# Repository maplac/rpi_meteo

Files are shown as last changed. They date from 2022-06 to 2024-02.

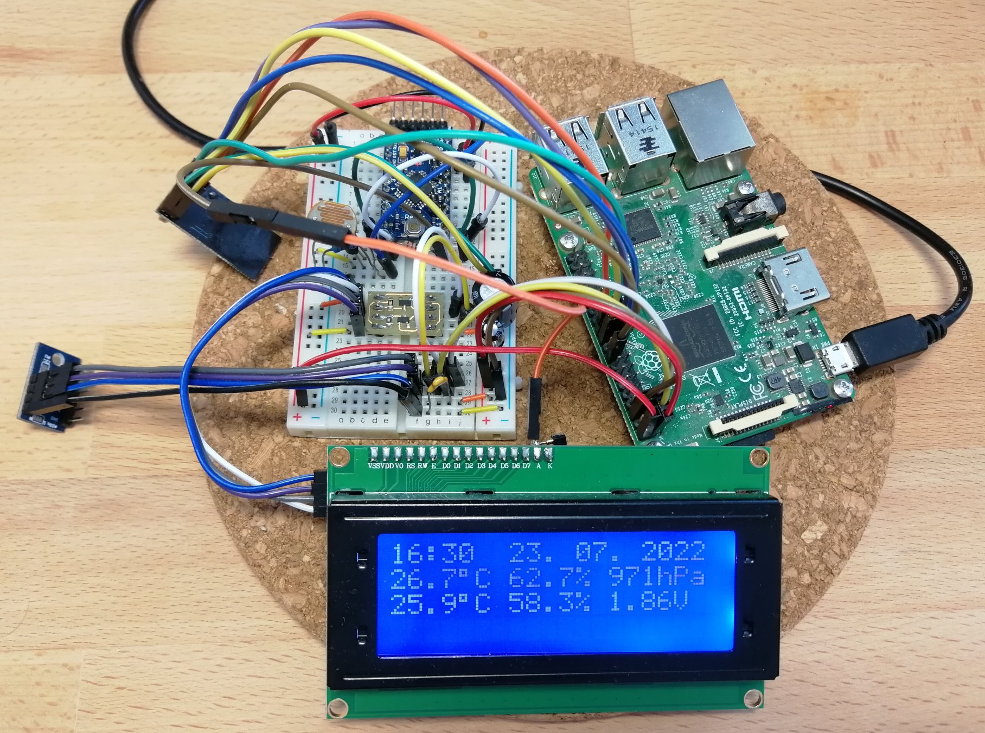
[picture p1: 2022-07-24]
photos/rpi_electronics_on_breadboard.jpg

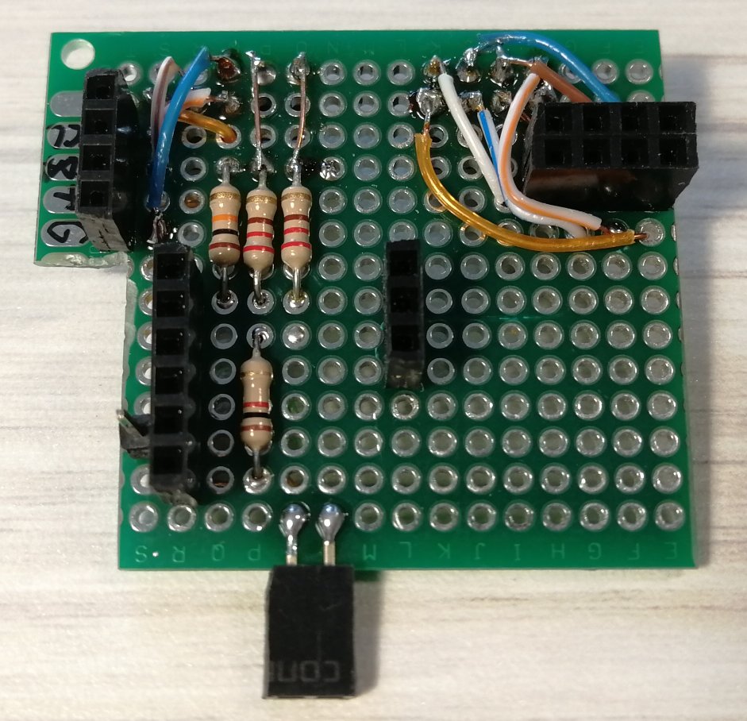
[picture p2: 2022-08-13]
photos/base_top_revA.jpg

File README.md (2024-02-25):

# rpi_meteo

Installation (incomplete)

Install Influx and Grafana.
https://simonhearne.com/2020/pi-influx-grafana/
"sudo apt install influxdb-client" if command influx doesn't work.

Add cron jobs.
$ crontab -e
* * * * * python3 /home/pi/rpi_meteo/python/bme280_reader.py >/dev/null 2>&1
# old driver for I2C 20x4 LCD display (not used enymore)
#* * * * * python3 /home/pi/rpi_meteo/python/lcd_driver.py >/dev/null 2>&1

Make sure the pigpiod service is enabled and running (required by rf24_receiver).
$ systemctl status pigpiod

Make the 'brightness' file editable by non-root user (required by backlight_driver).
sudo touch /etc/udev/rules.d/backlight-permissions.rules
sudo echo "SUBSYSTEM==\"backlight\",RUN+=\"/bin/chmod 666 /sys/class/backlight/%k/brightness /sys/class/backlight/%k/bl_power\"" > /etc/udev/rules.d/backlight-permissions.rules

Install service.
sudo cp /home/pi/rpi_meteo/python/rf24_receiver.service /lib/systemd/system/rf24_receiver.service
sudo systemctl start rf24_receiver
sudo systemctl enable rf24_receiver

sudo cp /home/pi/rpi_meteo/python/backlight_driver.service /lib/systemd/system/backlight_driver.service
sudo systemctl start backlight_driver
sudo systemctl enable backlight_driver

Install 'unclutter' to hide mouse cursor.
sudo apt install unclutter

Starting Grafana in web browser automatically after boot

Install Firefox (Chromium stopped working on my Rpi) $sudo apt-get install firefox-esr
Install ForceFull addon in Firefox. The addon automatically switches the Firefox to fullscreen mode.

Doesn't work:
Add following lines to file /home/pi/.config/lxsession/LXDE-pi/autostart
@lxpanel --profile LXDE-pi
@pcmanfm --desktop --profile LXDE-pi
#@xscreensaver -no-splash
point-rpi
@unclutter -idle 0
@firefox -url  http://localhost:3000/d/uZDC-7zgk/rpi_meteo-testing-simple?orgId=1&refresh=1m&kiosk
Do work:
Use firefox_starter.service or start_firefox_with_delay, one of them probably works.
Append "@unclutter -idle 0" to /etc/xdg/lxsession/LXDE-pi/autostart.

Modify InfluxDB settings to reduce CPU and RAM usage.
[data]
cache-max-memory-size = "512m"
max-concurrent-compactions = 2
[monitor]
store-enabled = false
From https://github.com/nikobockerman/ruuvitags-raspberrypi/tree/master/influxdb#initial-creation

Stop and disable telegraf.
systemctl disable telegraf

Grafana
Install Clock plugin.
sudo grafana-cli plugins install grafana-clock-panel
sudo systemctl restart grafana-server
Configure datasources

Arduino UNO project in test folder is based on https://github.com/bjarne-hansen/py-nrf24/blob/master/arduino/simple-sender/simple-sender.ino
Testing Python script rf24_receiver_01.py is based on https://github.com/bjarne-hansen/py-nrf24/blob/master/test/int-receiver.py

usermod -a - G gpio pi
usermod -a - G dialout pi
usermod -a - G i2c pi
Enable i2c and serial in "raspi-config".

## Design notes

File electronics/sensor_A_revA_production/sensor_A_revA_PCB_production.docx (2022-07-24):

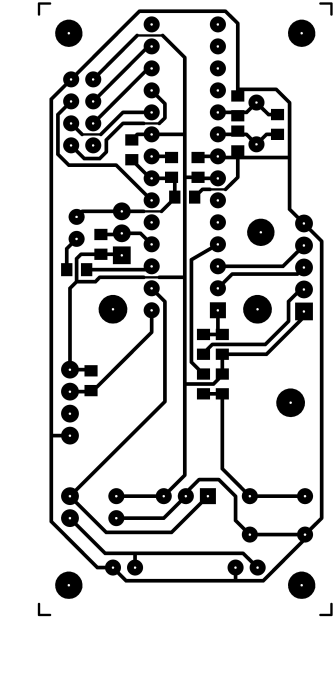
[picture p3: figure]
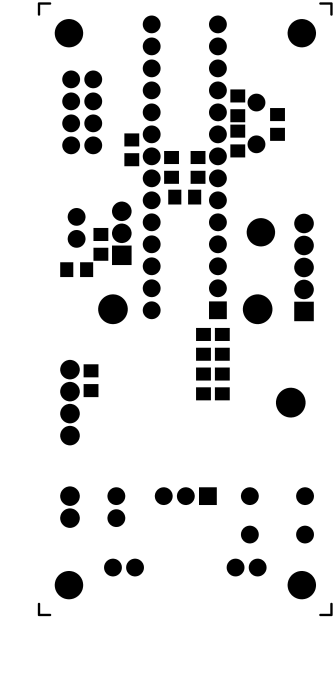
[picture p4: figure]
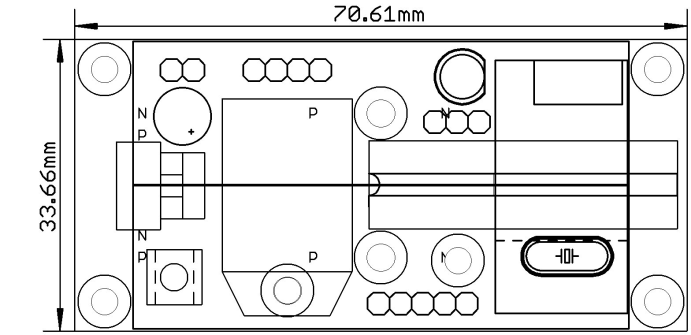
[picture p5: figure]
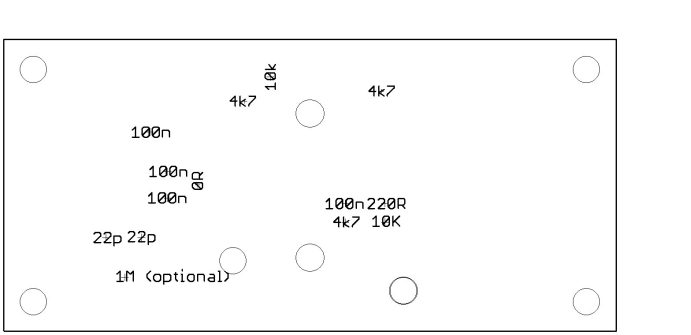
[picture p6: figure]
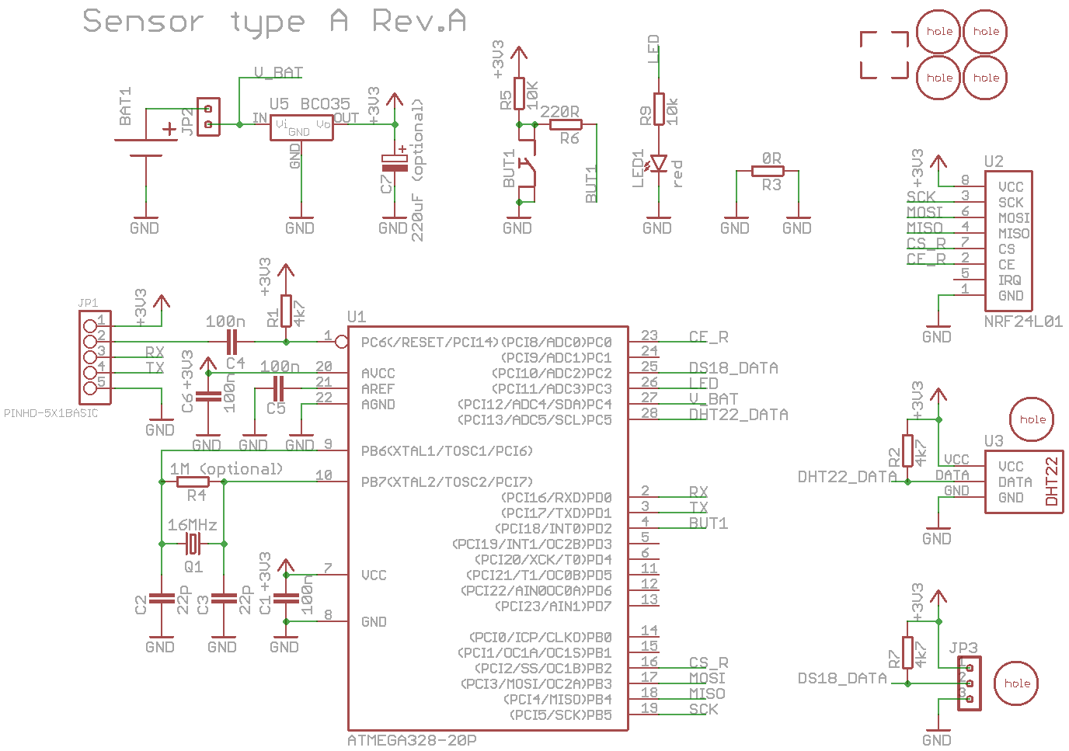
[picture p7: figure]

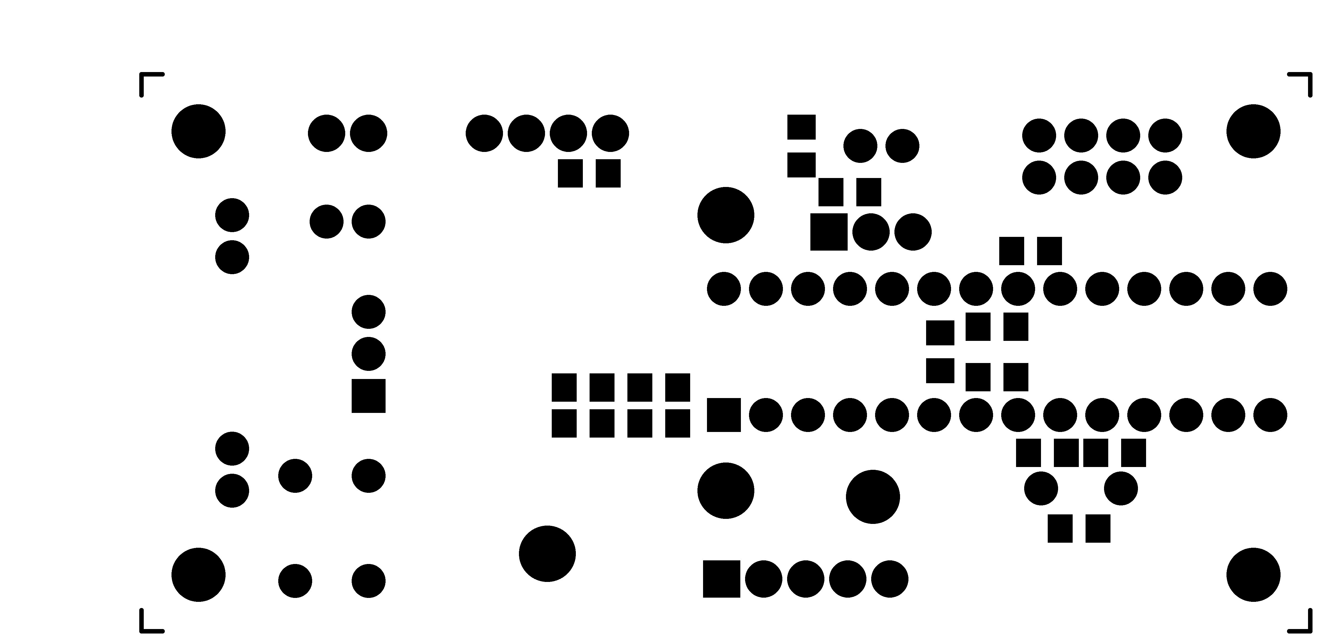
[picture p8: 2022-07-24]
electronics/sensor_A_revA_production/bottom_mask.jpg

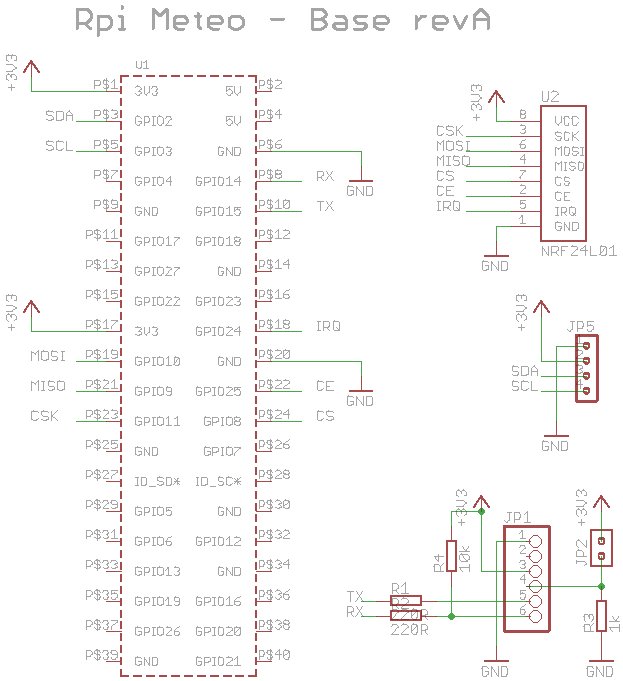
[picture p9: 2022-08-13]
electronics/base_revA_production/schematics.jpg

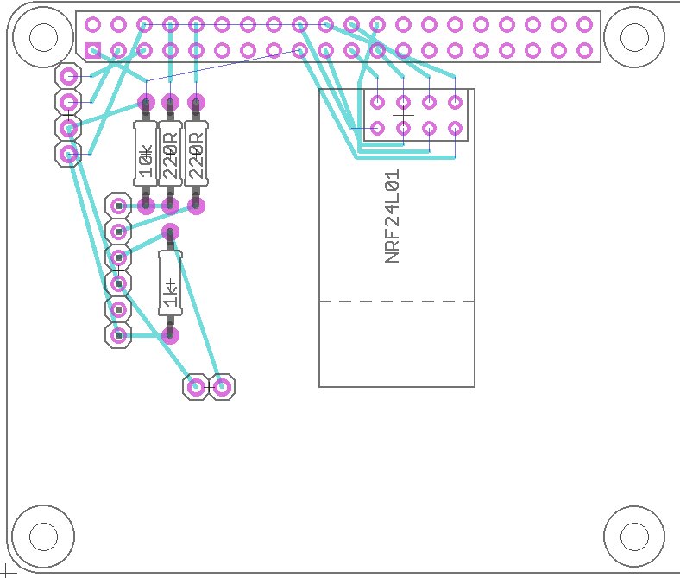
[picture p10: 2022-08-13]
electronics/base_revA_production/bottom&top.jpg

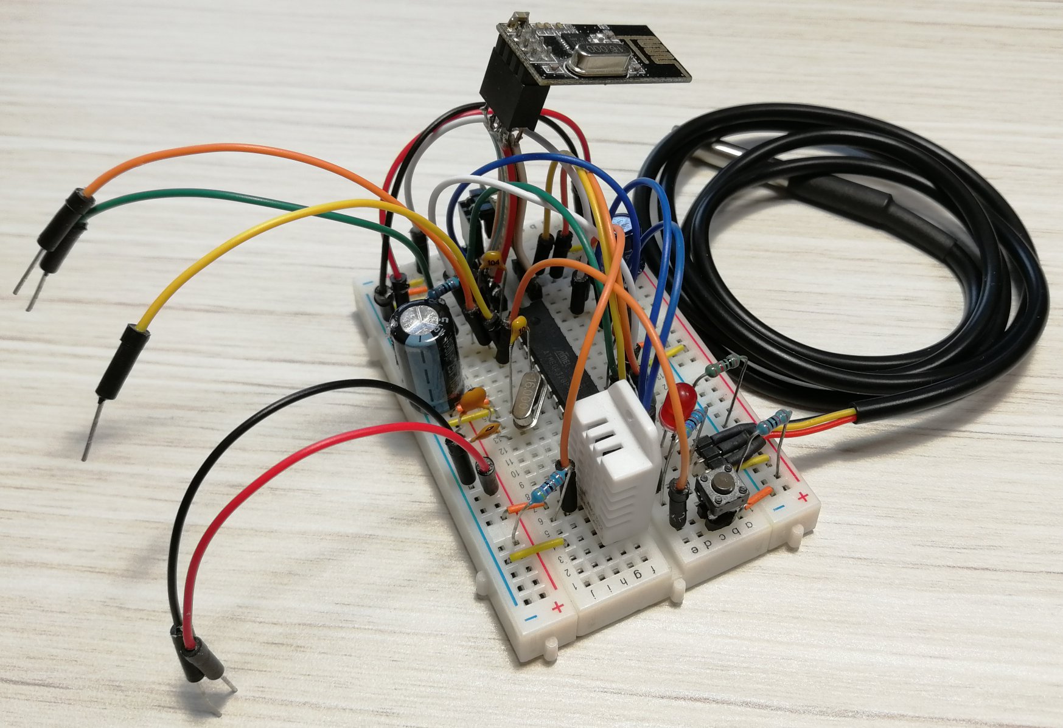
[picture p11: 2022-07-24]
photos/sensor_A_on_breadboard.jpg

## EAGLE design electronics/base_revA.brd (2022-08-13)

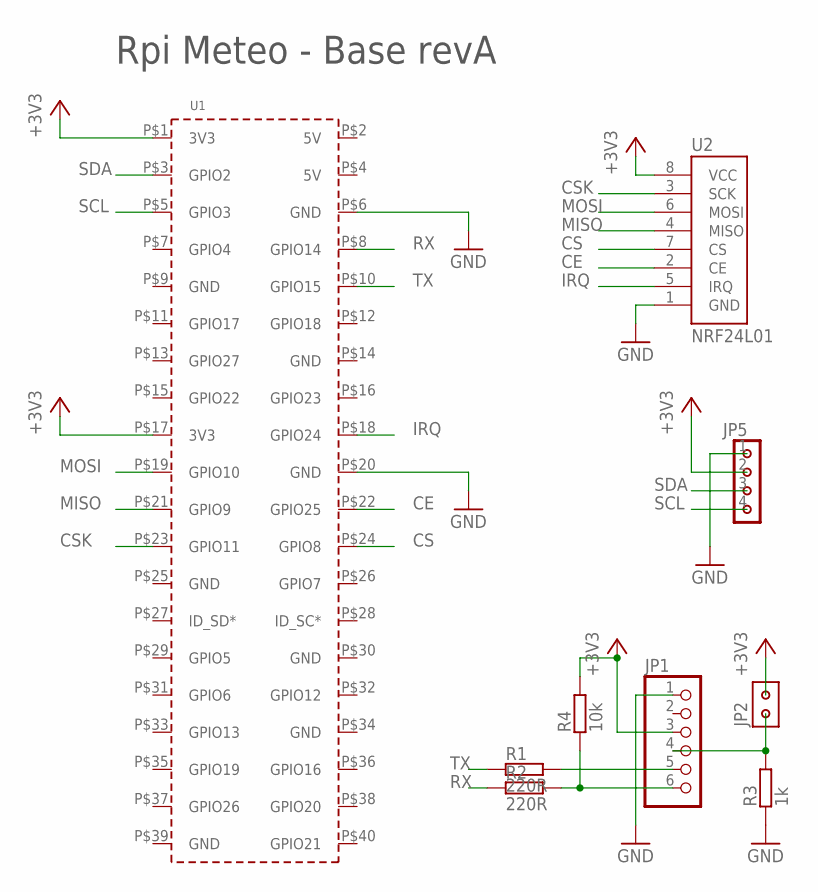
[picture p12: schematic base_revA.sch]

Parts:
JP1: PINHD-1X6; 1X06
JP2: PINHD-2X1
JP5: PINHD-4X1'BASIC'; 1X04
R1, R2: 220R; 0207-10
R3: 1k; 0207-10
R4: 10k; 0207-10
U1: RPI3_SIMPLE'FULL'; RPI3
U2: NRF24L01

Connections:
+3V3: JP1.3, JP2.1, JP5.2, R4.2, U1.P$1 (3V3), U1.P$17 (3V3), U2.8 (VCC)
CE: U1.P$22 (GPIO25), U2.2 (CE)
CS: U1.P$24 (GPIO8), U2.7 (CS)
CSK: U1.P$23 (GPIO11), U2.3 (SCK)
GND: JP1.1, JP5.1, R3.1, U1.P$6 (GND), U1.P$20 (GND), U2.1 (GND)
IRQ: U1.P$18 (GPIO24), U2.5 (IRQ)
MISO: U1.P$21 (GPIO9), U2.4 (MISO)
MOSI: U1.P$19 (GPIO10), U2.6 (MOSI)
unnamed: JP1.4, JP2.2, R3.2
unnamed: JP1.6, R2.2, R4.1
unnamed: JP1.5, R1.2
RX: R2.1, U1.P$8 (GPIO14)
SCL: JP5.4, U1.P$5 (GPIO3)
SDA: JP5.3, U1.P$3 (GPIO2)
TX: R1.1, U1.P$10 (GPIO15)

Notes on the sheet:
Rpi Meteo - Base revA

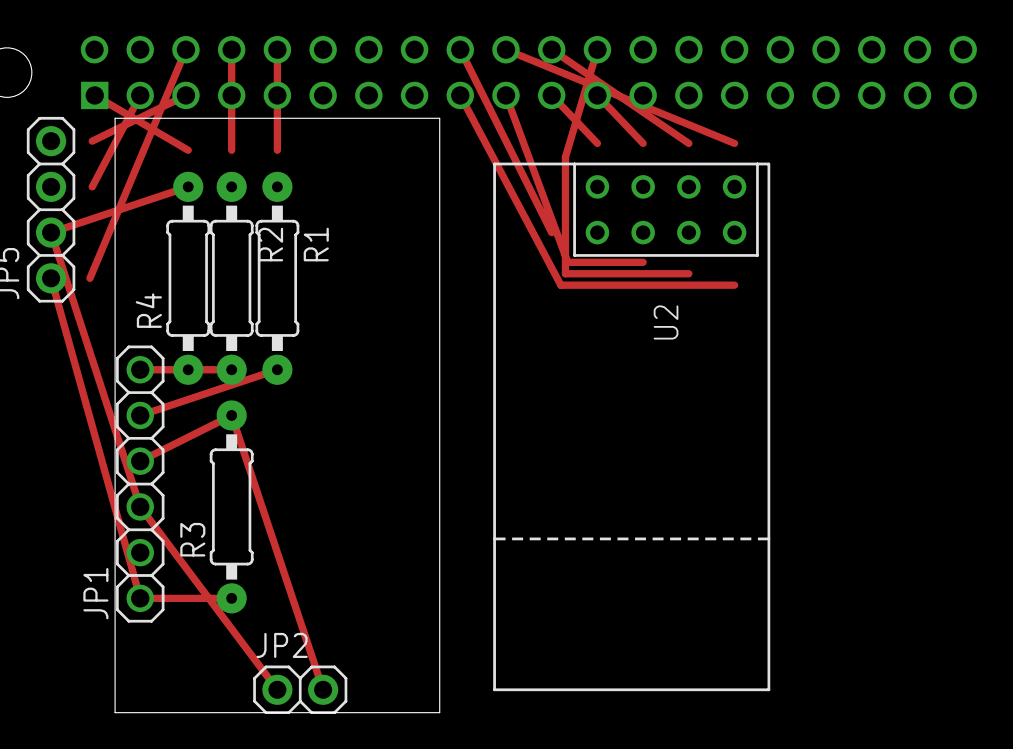
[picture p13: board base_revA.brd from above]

Board: 2 copper layers, 9 parts (0 on the bottom side), 15 nets.

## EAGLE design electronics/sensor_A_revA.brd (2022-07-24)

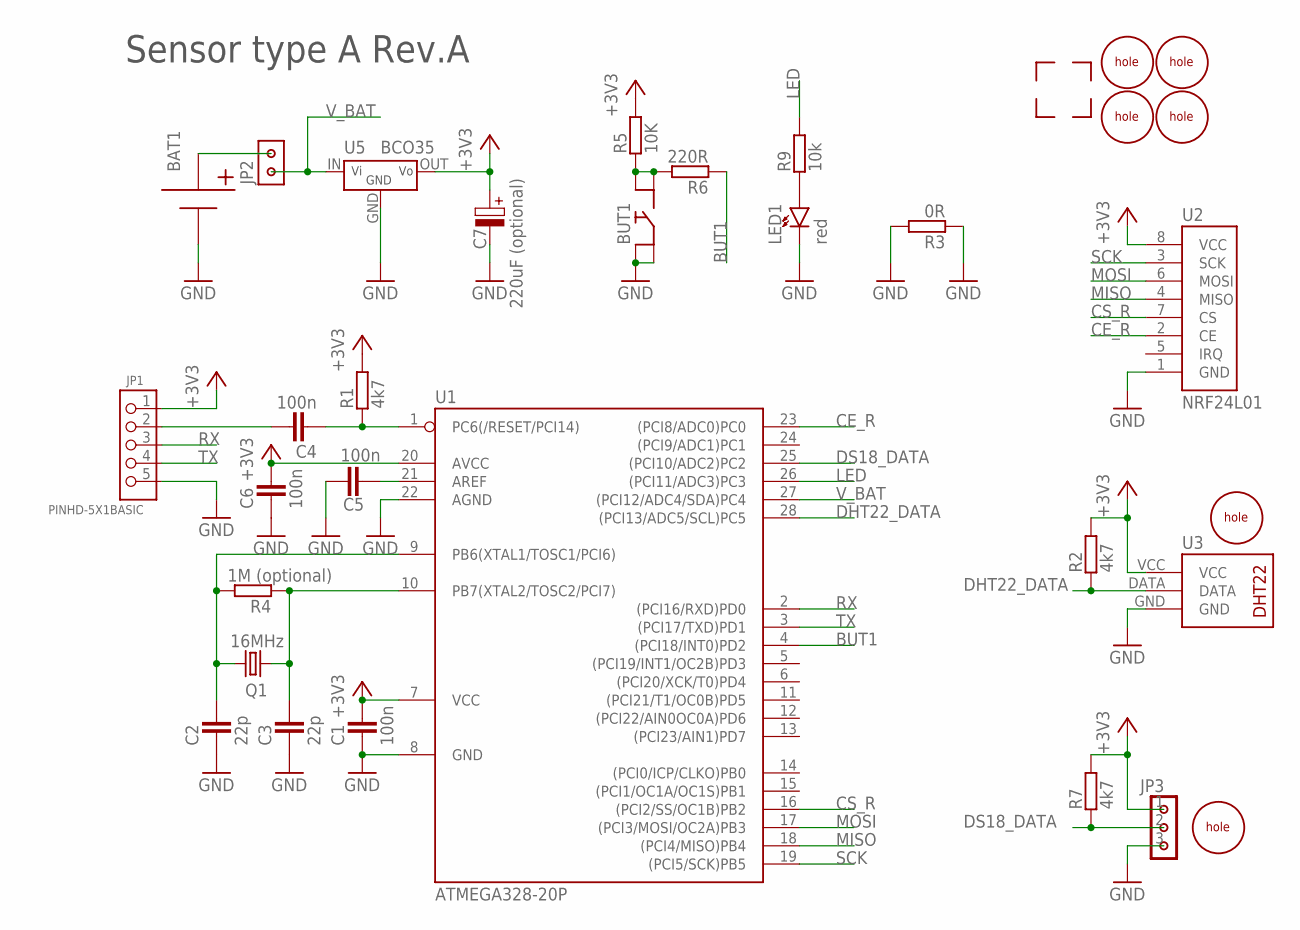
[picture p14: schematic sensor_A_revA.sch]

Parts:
BAT1: BATTERY_1X2X1XAAA; 1XAA_BATTERY_HOLDER_DOUBLE
BUT1: BUTTON'THT'; BUTTON
C1, C4, C5, C6: 100n; C0805
C2, C3: 22p; C0805
C7: 220uF (optional); ELYT-6MM5
JP1: PINHD-5X1BASIC; PINHD-5X1
JP2: PINHD-2X1
JP3: PINHD-3X1
LED1: red; LED5MM
Q1: 16MHz; HC49/S
R1, R2, R7: 4k7; R0805
R3: 0R; R0805
R4: 1M (optional); R0805
R5: 10K; R0805
R6: 220R; R0805
R9: 10k; R0805
U1: ATMEGA328-20P; DIL28-3
U2: NRF24L01
U3: DHT2290; DHT22/90
U5: BCO35
U$1, U$2, U$3, U$4: CORNER
U$5, U$6, U$7, U$8, U$9, U$10: HOLE

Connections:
+3V3: C1.2, C6.2, C7.+ (POS), JP1.1, JP3.1, R1.2, R2.2, R5.2, R7.2, U1.7 (VCC), U1.20 (AVCC), U2.8 (VCC), U3.VCC, U5.OUT (VOUT)
BUT1: R6.1, U1.4 ((PCI18/INT0)PD2)
CE_R: U1.23 ((PCI8/ADC0)PC0), U2.2 (CE)
CS_R: U1.16 ((PCI2/SS/OC1B)PB2), U2.7 (CS)
DHT22_DATA: R2.1, U1.28 ((PCI13/ADC5/SCL)PC5), U3.DATA
DS18_DATA: JP3.2, R7.1, U1.25 ((PCI10/ADC2)PC2)
GND: BAT1.N, BAT1.N1 (N), BUT1.2, BUT1.4, C1.1, C2.1, C3.1, C5.2, C6.1, C7.- (NEG), JP1.5, JP3.3, LED1.K, R3.1, R3.2, U1.8 (GND), U1.22 (AGND), U2.1 (GND), U3.GND, U5.GND
LED: R9.2, U1.26 ((PCI11/ADC3)PC3)
MISO: U1.18 ((PCI4/MISO)PB4), U2.4 (MISO)
MOSI: U1.17 ((PCI3/MOSI/OC2A)PB3), U2.6 (MOSI)
unnamed: C3.2, Q1.1, R4.1, U1.10 (PB7(XTAL2/TOSC2/PCI7))
unnamed: C4.1, R1.1, U1.1 (PC6(/RESET/PCI14))
unnamed: C2.2, Q1.2, R4.2, U1.9 (PB6(XTAL1/TOSC1/PCI6))
unnamed: C5.1, U1.21 (AREF)
unnamed: C4.2, JP1.2
unnamed: BAT1.P, BAT1.P1, JP2.1
unnamed: BUT1.1, BUT1.3, R5.1, R6.2
unnamed: LED1.A, R9.1
RX: JP1.3, U1.2 ((PCI16/RXD)PD0)
SCK: U1.19 ((PCI5/SCK)PB5), U2.3 (SCK)
TX: JP1.4, U1.3 ((PCI17/TXD)PD1)
V_BAT: JP2.2, U1.27 ((PCI12/ADC4/SDA)PC4), U5.IN (VIN)

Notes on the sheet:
Sensor type A Rev.A

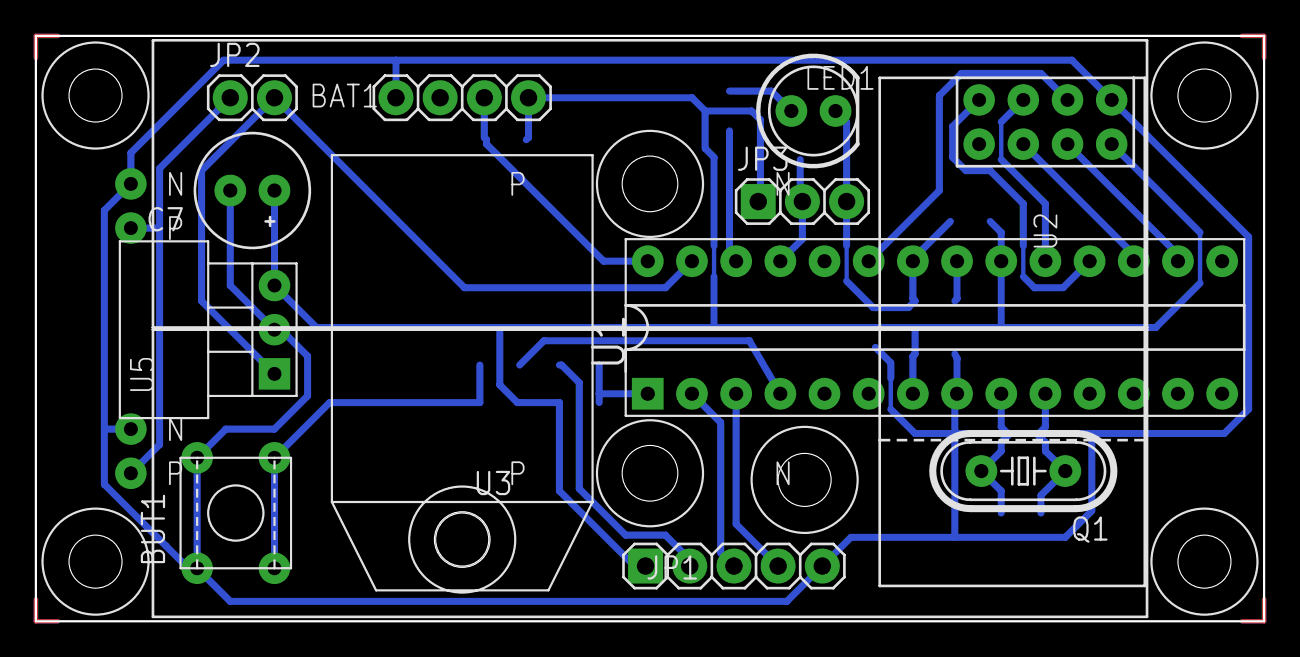
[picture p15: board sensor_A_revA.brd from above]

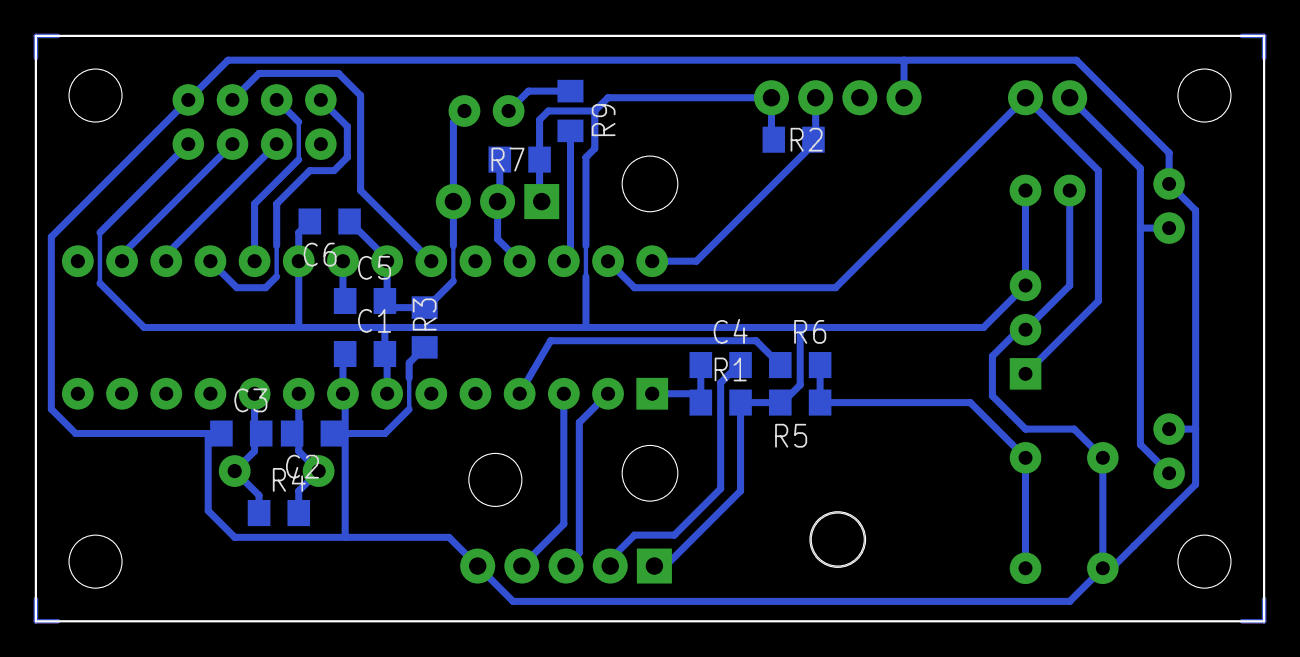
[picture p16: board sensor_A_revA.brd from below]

Board: 2 copper layers, 70.6 x 33.7 mm, 36 parts (14 on the bottom side), 22 nets.

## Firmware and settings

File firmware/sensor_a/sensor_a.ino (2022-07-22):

#include <DHT.h>
#include<Vcc.h>
#include <JeeLib.h>
#include <printf.h>
#include <RF24.h>
#include <OneWire.h> 
#include <DallasTemperature.h>

//#define DEBUG_ENABLED 1
#define USE_DHT22     1
#define USE_DS18      1

#define DEVICE_ID   1
#define PIN_VOLTAGE A4
#define PIN_BUTTON  2
#define PIN_LED     17

// Cretate NRF24L01 radio.
RF24 radio(14, 10);// CE pin, CSN pin
byte rf24_tx[6] = "RpiMe";    // Address used when transmitting data.
byte payload[32];             // Payload bytes. Used both for transmitting and receiving

#ifdef USE_DHT22
  // Create DHT sensor
  DHT dht(19, DHT22);// pin number, DHT type (DHT11, DHT12, DHT21, DHT22 (AM2302), AM2301)
#endif

#ifdef USE_DS18
  // Create DS18B20 sensor
  OneWire oneWire(16);// pin number
  DallasTemperature ds18(&oneWire);
#endif

// flags
volatile bool isTimeout = false;
volatile bool isButton = false;

uint32_t counterSendFailed = 0;
uint8_t counterPackets = 0;
uint8_t buttonLastState = 3;
uint32_t counterSendAttempts = 0;

void measureAndSend(void);

ISR(WDT_vect) {
  Sleepy::watchdogEvent();
  isTimeout = true;
}

void buttonInt(void){
  isButton = true;
}

void setup() {
  pinMode(PIN_BUTTON, INPUT);
  pinMode(PIN_LED, OUTPUT);
  digitalWrite(PIN_LED, LOW);
  attachInterrupt(digitalPinToInterrupt(PIN_BUTTON), buttonInt, FALLING);
  analogReference(DEFAULT);//EXTERNAL

  #ifdef DEBUG_ENABLED
    Serial.begin(115200);
    printf_begin();
  #endif

  // Configure the NRF24 tranceiver.
  Serial.println("Configure NRF24 ...");
  radio.begin();
  radio.enableDynamicPayloads();
  radio.setAutoAck(true);
  radio.setPALevel(RF24_PA_MAX);
  radio.setRetries(5, 15);//Delay bewteen retries, 1..15.  Multiples of 250µs. Number of retries, 1..15.
  radio.setDataRate(RF24_250KBPS);// RF24_2MBPS, RF24_1MBPS, RF24_250KBPS
  radio.setChannel(100);// 0 ... 125
  radio.setCRCLength(RF24_CRC_16);// RF24_CRC_DISABLED, RF24_CRC_8, RF24_CRC_16 for 16-bit
  radio.setPayloadSize(32);// Max. 32 bytes.
  radio.openWritingPipe(rf24_tx);
  radio.stopListening();

  #ifdef DEBUG_ENABLED
    // Show debug information for NRF24 tranceiver.
    radio.printDetails();
  #endif

  #ifdef USE_DHT22
    // Initialise the DHT sensor.
    dht.begin();
  #endif

  isTimeout = true;
}

void loop() {
  
  // make sure everything is finished before go to sleep
  delay(20);

  // wait for button press or timer
  if (!isButton && !isTimeout){
    Sleepy::loseSomeTime(60000);
  }

  if (isButton) {
    delay(100);// debounce
    if (!digitalRead(PIN_BUTTON)) {
      measureAndSend();
    }
    isButton = false;
  }
  if (isTimeout) {
    isTimeout = false;
    measureAndSend();
  }
}

void measureAndSend(void) {
   
  float t, h, v, t2;
  v = analogRead(PIN_VOLTAGE) * 3.3 / 1024.0;
  #ifdef USE_DS18
    ds18.requestTemperatures();
  #endif
  #ifdef USE_DHT22
    h = dht.readHumidity();
    t = dht.readTemperature();
  #else
    h = 0.0;
    t = 0.0;
  #endif
  #ifdef USE_DS18
    t2 = ds18.getTempCByIndex(0);
  #else
    t2 = 0.0;
  #endif

  #ifdef DEBUG_ENABLED
    // Report the temperature and humidity.    
    Serial.print("temperature = "); Serial.print(t); 
    Serial.print(", temperature2 = "); Serial.print(t2);
    Serial.print(", humidity = "); Serial.print(h);
    Serial.print(", voltage = "); Serial.print(v);
    Serial.print(", lostPackets = "); Serial.println(counterSendFailed);
  #endif

  digitalWrite(PIN_LED, HIGH);

  payload[0] = DEVICE_ID; // id
  payload[1] = counterPackets; // packet counter
  payload[2] = 0; // packet type
  payload[3] = 0; // reserved

  float *packetF = (float*) &payload; //size_of(float)=4
  packetF[1] = t;
  packetF[2] = t2;
  packetF[3] = h;
  packetF[4] = v;

  uint32_t *packetUI23 = (uint32_t*) &payload;
  packetUI23[5] = counterSendFailed;

  if (radio.write(payload, 32)) {
    counterSendFailed = 0;
    #ifdef DEBUG_ENABLED
      Serial.print("Transfer OK. Retries="); Serial.println(radio.getARC());
    #endif
  } else {
    counterSendFailed++;
    #ifdef DEBUG_ENABLED
      Serial.print("Transfer FAILED. Retries="); Serial.println(radio.getARC());
    #endif
  }
  counterPackets++;

  radio.startListening();
  radio.stopListening();
  digitalWrite(PIN_LED, LOW);
}

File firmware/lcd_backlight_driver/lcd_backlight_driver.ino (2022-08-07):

// Board: Arduino Pro Mini
#include<SoftwareSerial.h>
#include <printf.h>

//#define DEBUG_ENABLED 1

#define AVG_TARGET  10
#define PIN_IN      A3
#define PIN_RX       15
#define PIN_TX       16

SoftwareSerial SerialSoft(PIN_RX, PIN_TX);
int sum;
int avgCounter;

void setup() {
  #ifdef DEBUG_ENABLED
    Serial.begin(115200);
    printf_begin();
  #endif
  
  pinMode(PIN_RX, INPUT);
  pinMode(PIN_TX, OUTPUT);
  SerialSoft.begin(9600);
  
  sum = analogRead(PIN_IN);
  avgCounter = 1;
}

void loop() {
  sum += analogRead(PIN_IN);
  avgCounter++;
  if (avgCounter == AVG_TARGET) {
    sum /= (AVG_TARGET * 4);
    if (sum < 0) {
      sum = 0;
    }
    if (sum > 255) {
      sum = 255;
    }
    SerialSoft.write((byte) sum);
    #ifdef DEBUG_ENABLED
      Serial.println((byte) sum);
    #endif
    sum = 0;
    avgCounter = 0;
  }
  delay(100);
}

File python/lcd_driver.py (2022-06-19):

from RPLCD import i2c
from influxdb import InfluxDBClient
import time

bme280_valid = False
bme280_t = 0
bme280_p = 0
bme280_h = 0

dht22_valid = False
dht22_t = 0
dht22_v = 0
dht22_h = 0

try:
    client = InfluxDBClient(host='192.168.0.104', port=8086, database='home')
    res = client.query('SELECT mean("temperature"),mean("pressure"),mean("humidity") '
                       'FROM "test" WHERE ("name" = \'bme280\') AND time >= now() - 5m')
    #print(res.raw)
    for point in res.get_points():
        bme280_t = point['mean']
        bme280_p = point['mean_1']
        bme280_h = point['mean_2']
        bme280_valid = True
        break
        
    res = client.query('SELECT mean("temperature"),mean("humidity"),mean("voltage") '
                       'FROM "test" WHERE ("name" = \'dht22\') AND time >= now() - 5m')
    
    for point in res.get_points():
        dht22_t = point['mean']
        dht22_h = point['mean_1']
        dht22_v = point['mean_2']
        dht22_valid = True
        break
except Exception as e:
    print("Error: ", e.__class__, ", ", e)


lcd = i2c.CharLCD('PCF8574', 0x27, port=1, charmap='A00', cols=20, rows=4)
lcd.cursor_pos = (0, 0)

t = time.localtime()
time_str = "{:02d}".format(t.tm_hour) + ":" + "{:02d}".format(t.tm_min)
time_str += "  {:02d}".format(t.tm_mday) + ". " + "{:02d}".format(t.tm_mon) + ". " + str(t.tm_year)
lcd.write_string(time_str)
lcd.crlf()

if bme280_valid:
    lcd.write_string("{:.1f}".format(bme280_t) + chr(176) + "C ")
    lcd.write_string("{:.1f}".format(bme280_h) + chr(37) + " ")
    lcd.write_string("{:.0f}".format(bme280_p) + "hPa")
else:
    lcd.write_string("no data")

lcd.crlf()

if dht22_valid:
    lcd.write_string("{:.1f}".format(dht22_t) + chr(176) + "C ")
    lcd.write_string("{:.1f}".format(dht22_h) + chr(37) + " ")
    lcd.write_string("{:.2f}".format(dht22_v) + "V")
else:
    lcd.write_string("no data")

#lcd.crlf()

lcd.close()

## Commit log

2022-05-05 added test project for Arduino UNO
2022-05-18 modified Arduino test
2022-05-18 added LCD driver
2022-05-23 added firmware for LCD backlight driver
2022-05-31 added firmware for sensor type A
2022-06-19 modified FW for sensor A
2022-06-19 added RF24 receiver for remote sensors
2022-06-19 LCD driver shows values from remote sensors
2022-07-22 modified FW for sensor A - added support for DS18B20
2022-07-23 RF24 receiver can process DS18B20 temperature from sensor A
2022-07-24 added PCB for sensor A
    [sensor_A_revA.brd, sensor_A_revA.sch]
2022-07-26 added firmware that forwards data from RF24 to UART
2022-07-26 added script that receives data from UART
2022-07-31 added testing script for reading pin status
2022-07-31 modified pin interrupt in RF24 receiver
2022-08-07 modified FW for LCD backlight driver
2022-08-13 added: PCB for base board that is mounted on the Rpi
    [base_revA.brd, base_revA.sch]
2024-02-25 migration to Raspberry Pi 4
